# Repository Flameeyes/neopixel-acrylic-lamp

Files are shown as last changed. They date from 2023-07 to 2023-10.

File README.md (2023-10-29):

<!--
SPDX-FileCopyrightText: 2020 Diego Elio Pettenò

SPDX-License-Identifier: MIT
-->

# Neopixel Acrylic Lamp

This repository contains Eagle PCB dsigns and 3D objects to build a lamp hosting an acrylic
cutout, similar to the many "3D effect" lamps that you can buy on most online stores by now.

Please note that while rev3 boards appear to be working, the 3D objects are still untested
and the design is still up in the air.

## Further References

Refer to my [blog](https://flameeyes.blog/tag/acrylic-lamps/) for
details.

## License

Copyright 2020 Diego Elio Pettenò

Permission is hereby granted, free of charge, to any person obtaining a copy of this
software and associated documentation files (the "Software"), to deal in the Software
without restriction, including without limitation the rights to use, copy, modify,
merge, publish, distribute, sublicense, and/or sell copies of the Software, and to
permit persons to whom the Software is furnished to do so, subject to the following
conditions:

The above copyright notice and this permission notice shall be included in all copies or
substantial portions of the Software.

THE SOFTWARE IS PROVIDED "AS IS", WITHOUT WARRANTY OF ANY KIND, EXPRESS OR IMPLIED,
INCLUDING BUT NOT LIMITED TO THE WARRANTIES OF MERCHANTABILITY, FITNESS FOR A PARTICULAR
PURPOSE AND NONINFRINGEMENT. IN NO EVENT SHALL THE AUTHORS OR COPYRIGHT HOLDERS BE
LIABLE FOR ANY CLAIM, DAMAGES OR OTHER LIABILITY, WHETHER IN AN ACTION OF CONTRACT, TORT
OR OTHERWISE, ARISING FROM, OUT OF OR IN CONNECTION WITH THE SOFTWARE OR THE USE OR
OTHER DEALINGS IN THE SOFTWARE.

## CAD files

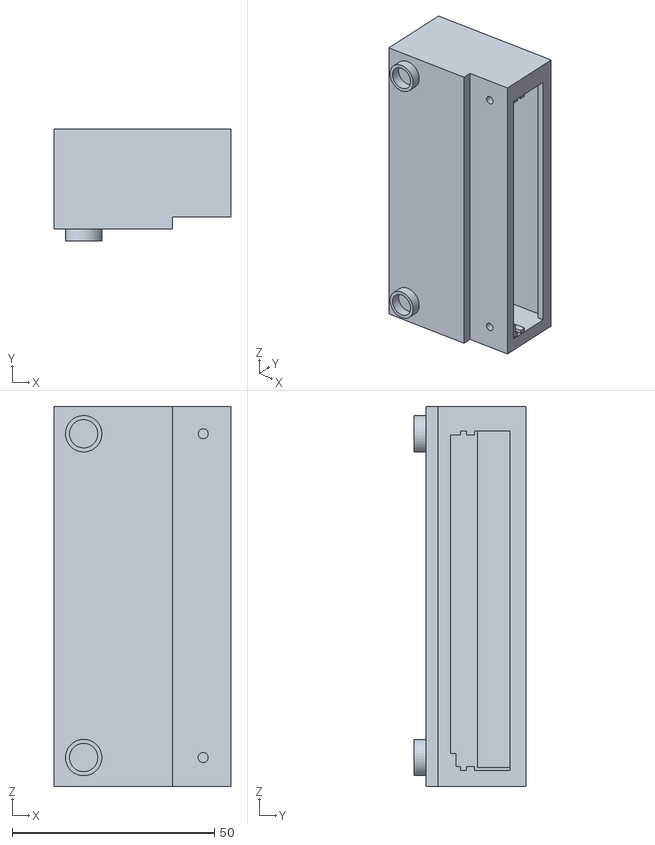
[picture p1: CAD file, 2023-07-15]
base/rev3/main-body.stl
43.7 x 27.7 x 93.9

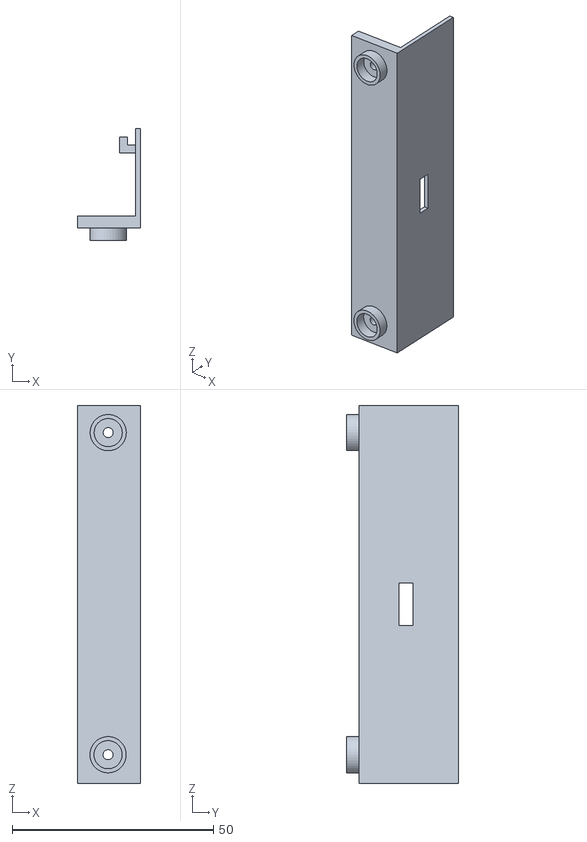
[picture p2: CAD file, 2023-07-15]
base/rev3/door-slot.stl
15.7 x 27.7 x 93.9

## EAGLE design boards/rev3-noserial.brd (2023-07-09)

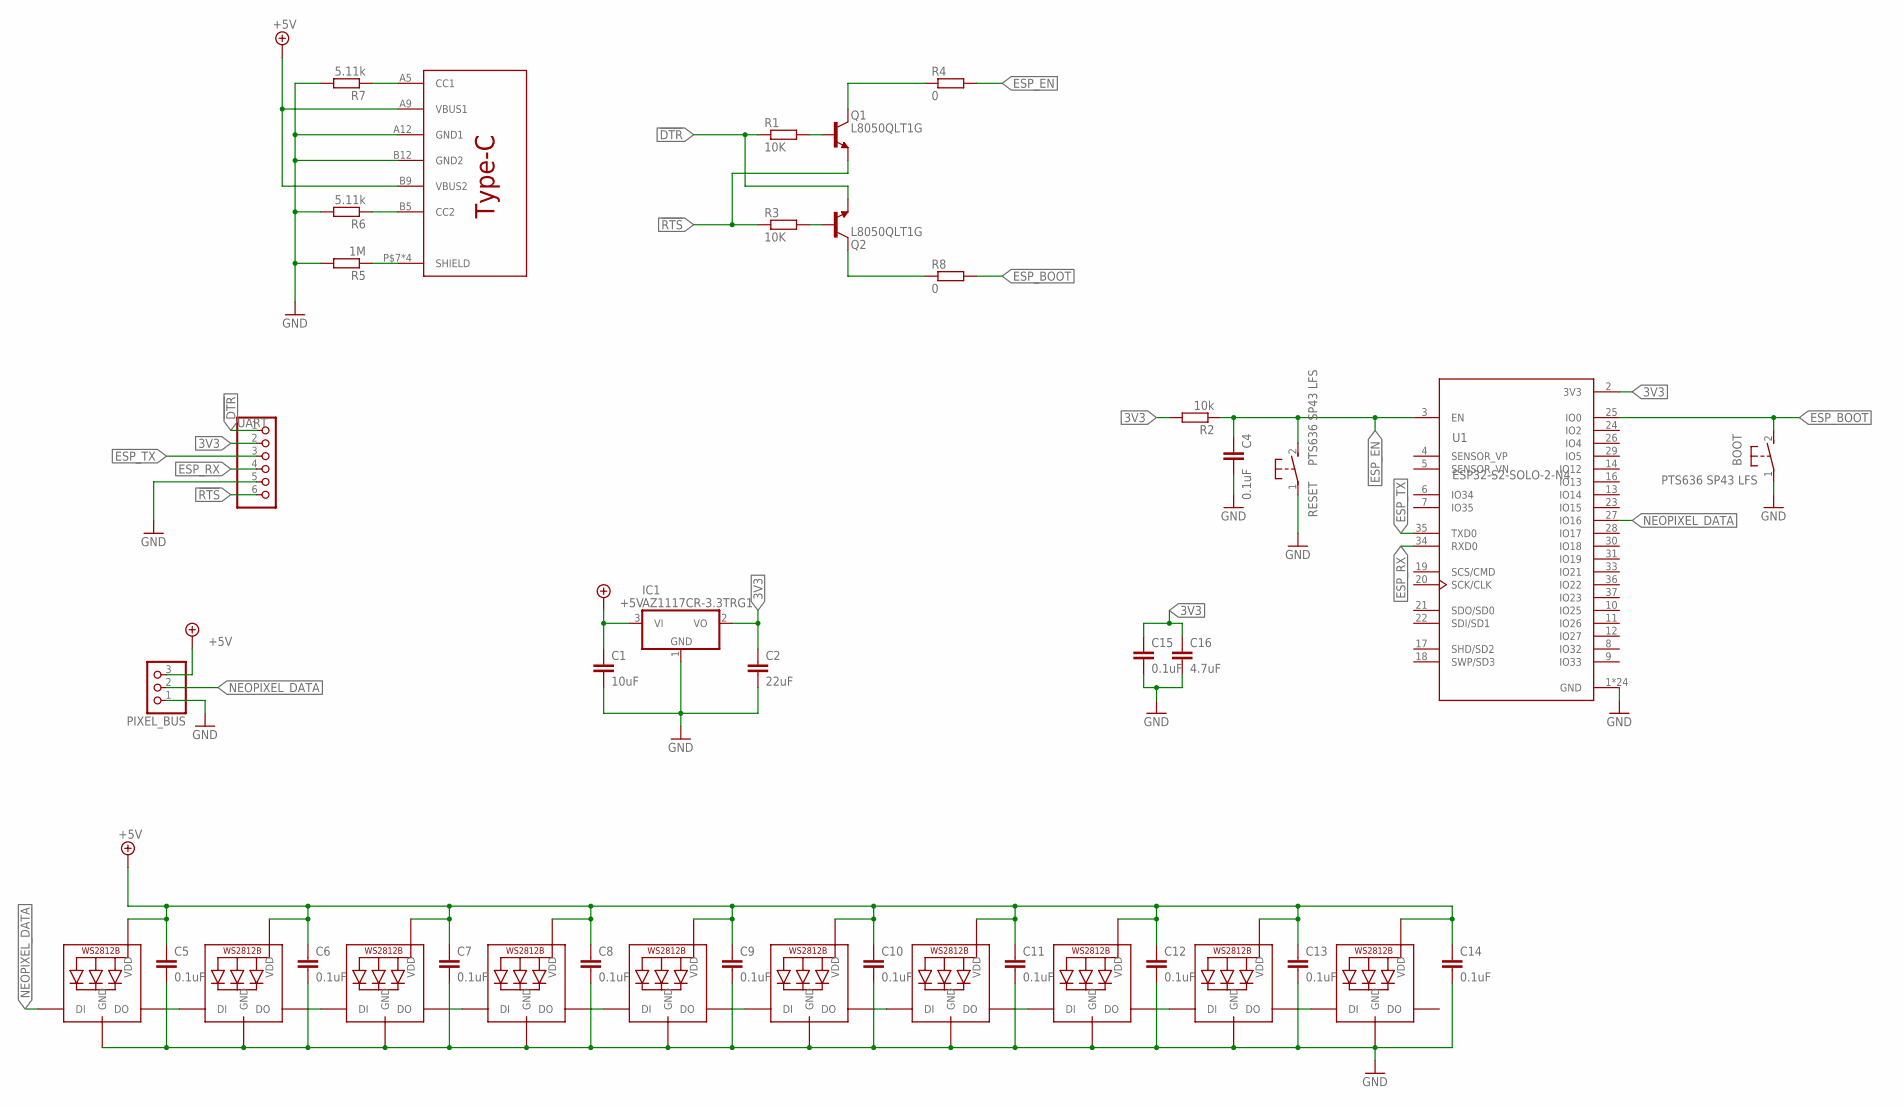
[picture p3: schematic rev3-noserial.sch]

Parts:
BOOT: PTS636 SP43 LFS; PTS636SP43LFS
C1: 10uF; C0805
C2: 22uF; C0805
C4, C5, C6, C7, C8, C9, C10, C11, C12, C13, C14, C15: 0.1uF; C0805
C16: 4.7uF; C0805
IC1: AZ1117CR-3.3TRG1; SOT89
LED1, LED2, LED3, LED4, LED5, LED6, LED7, LED8, LED9, LED10: WS2812B5050; WS2812B
PIXEL_BUS: PINHD-1X3; 1X03
Q1, Q2: L8050QLT1G; SOT95P237X112-3N
R1, R3: 10K; R0805
R2: 10k; R0805
R4, R8: 0; R0805
R5: 1M; R0805
R6, R7: 5.11k; R0805
RESET: PTS636 SP43 LFS; PTS636SP43LFS
U1: ESP32-S2-SOLO-2-N4; MODULE_ESP32-WROOM-32D
U$1: TYPEC-DB-104PWB
UART: PINHD-1X6; 1X06

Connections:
3V3: C2.1, C15.1, C16.1, IC1.2 (VO), R2.2, U1.2 (3V3), UART.2
!DTR: Q2.2 (E), R1.1, UART.1
!RTS: Q1.2 (E), R3.1, UART.6
+5V: C1.1, C5.1, C6.1, C7.1, C8.1, C9.1, C10.1, C11.1, C12.1, C13.1, C14.1, IC1.3 (VI), LED1.1-VDD (VDD), LED2.1-VDD (VDD), LED3.1-VDD (VDD), LED4.1-VDD (VDD), LED5.1-VDD (VDD), LED6.1-VDD (VDD), LED7.1-VDD (VDD), LED8.1-VDD (VDD), LED9.1-VDD (VDD), LED10.1-VDD (VDD), PIXEL_BUS.3, U$1.A9 (VBUS1), U$1.B9 (VBUS2)
ESP_BOOT: BOOT.2, R8.2, U1.25 (IO0)
ESP_EN: C4.1, R2.1, R4.2, RESET.2, U1.3 (EN)
ESP_RX: U1.34 (RXD0), UART.4
ESP_TX: U1.35 (TXD0), UART.3
GND: BOOT.1, C1.2, C2.2, C4.2, C5.2, C6.2, C7.2, C8.2, C9.2, C10.2, C11.2, C12.2, C13.2, C14.2, C15.2, C16.2, IC1.1 (GND), LED1.3-GND (GND), LED2.3-GND (GND), LED3.3-GND (GND), LED4.3-GND (GND), LED5.3-GND (GND), LED6.3-GND (GND), LED7.3-GND (GND), LED8.3-GND (GND), LED9.3-GND (GND), LED10.3-GND (GND), PIXEL_BUS.1, R5.2, R6.2, R7.2, RESET.1, U1.1 (GND), U1.15 (GND), U1.38 (GND), U1.39_1 (GND), U1.39_2 (GND), U1.39_3 (GND), U1.39_4 (GND), U1.39_5 (GND), U1.39_6 (GND), U1.39_7 (GND), U1.39_8 (GND), U1.39_9 (GND), U1.39_10 (GND), U1.39_11 (GND), U1.39_12 (GND), U1.39_13 (GND), U1.39_14 (GND), U1.39_15 (GND), U1.39_16 (GND), U1.39_17 (GND), U1.39_18 (GND), U1.39_19 (GND), U1.39_20 (GND), U1.39_21 (GND), U$1.A12 (GND1), U$1.B12 (GND2), UART.5
unnamed: R6.1, U$1.B5 (CC2)
unnamed: R5.1, U$1.P$7 (SHIELD), U$1.P$8 (SHIELD), U$1.P$9 (SHIELD), U$1.P$10 (SHIELD)
unnamed: R7.1, U$1.A5 (CC1)
unnamed: LED2.2-DOUT (DO), LED3.4-DIN (DI)
unnamed: Q1.1 (B), R1.2
unnamed: Q2.1 (B), R3.2
unnamed: LED3.2-DOUT (DO), LED4.4-DIN (DI)
unnamed: Q1.3 (C), R4.1
unnamed: Q2.3 (C), R8.1
unnamed: LED4.2-DOUT (DO), LED5.4-DIN (DI)
unnamed: LED5.2-DOUT (DO), LED6.4-DIN (DI)
unnamed: LED6.2-DOUT (DO), LED7.4-DIN (DI)
unnamed: LED7.2-DOUT (DO), LED8.4-DIN (DI)
unnamed: LED8.2-DOUT (DO), LED9.4-DIN (DI)
unnamed: LED9.2-DOUT (DO), LED10.4-DIN (DI)
unnamed: LED1.2-DOUT (DO), LED2.4-DIN (DI)
NEOPIXEL_DATA: LED1.4-DIN (DI), PIXEL_BUS.2, U1.27 (IO16)

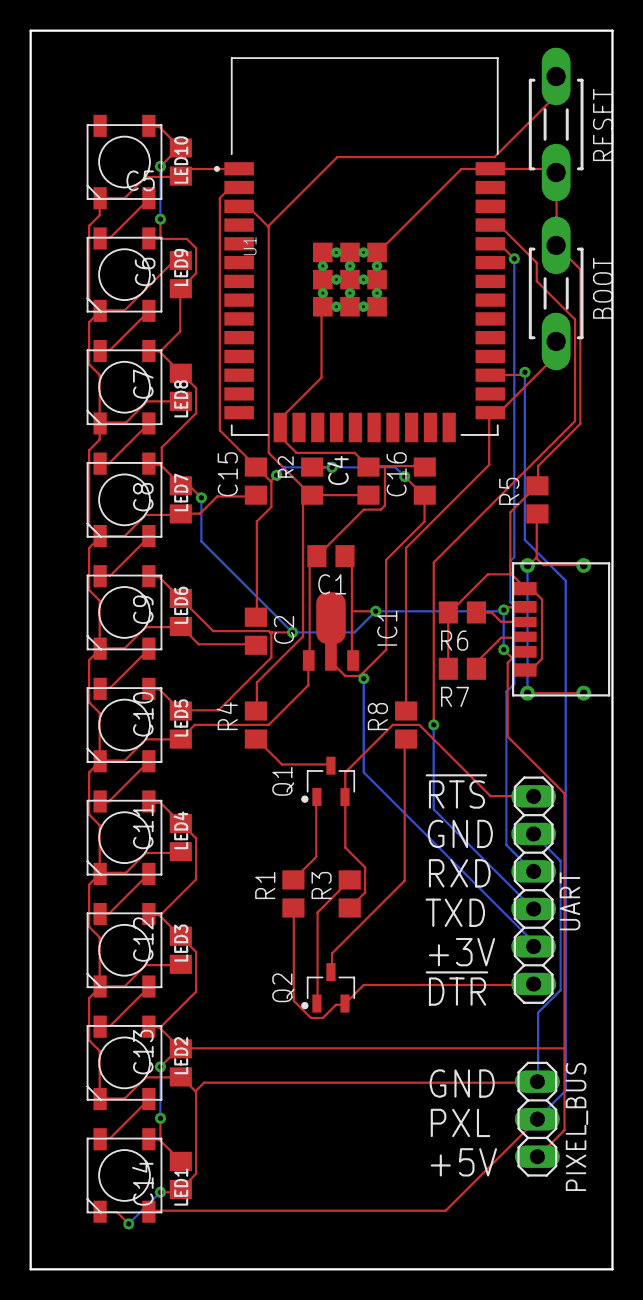
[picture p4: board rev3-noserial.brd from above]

Board: 2 copper layers, 39.4 x 83.8 mm, 42 parts (0 on the bottom side), 26 nets.

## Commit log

2020-07-18 Add the d-board schematics.
    [d-board.brd, d-board.sch]
2020-07-20 Update board to rev.2
    Fixes CP2104 REGIN not connected to +5V.
    Replaces the mis-pinned 3535 neopixel with the 5050 part that is correct instead.
    [d-board.brd, d-board.sch]
2020-07-24 Replace the microUSB connector.
    Instead of the Wurth part that seems to be harder to find, use a SnapEDA for an Amphenol 10103594-0001LF connector that appears easier to source.
    [d-board.brd, d-board.sch]
2020-08-31 Make it possible to program the ESP32 via serial.
    This includes RESET and BOOT pushbuttons to control a solder ESP32, and re-wires the RTS/DTR to control the boot mode of the board for compatibility with the esptool command line.
    [d-board.brd, d-board.sch]
2020-09-02 Replace the CP2104 with a CP2102
    The CP2104 is getting harder to source, the CP2102 is pretty much equivalent, but requires more components.
    [d-board.brd, d-board.sch]
2020-09-12 Use net names instead of very long connections.
    This allows an easier read of the diagram.
    [d-board.brd, d-board.sch]
2023-07-02 Introduce rev3 and remove non-functional d-board.
    The d-shaped board never worked, remove it.
    The new rev3 is not meant to replace the existing boards in the AliExpress bases but rather includes its own 3D-printed base.
    [d-board.brd, door-slot.stl, main-body.stl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]
2023-07-09 Update the no-serial design for autoprogram.
    This includes the same design block as the ESP32 WROOM-like modules, which means it should be possible to auto-program the boards without needing to solder in buttons.
    [rev3-noserial.brd, rev3-noserial.sch]
2023-07-15 Update base.
    This raises the feet to make sure the screw hides properly behind it, and tries to improve on the slot in mechanism for the door.
    [door-slot.stl, main-body.stl]

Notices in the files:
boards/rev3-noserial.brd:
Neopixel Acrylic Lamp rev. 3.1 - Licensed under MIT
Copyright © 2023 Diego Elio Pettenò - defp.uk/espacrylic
